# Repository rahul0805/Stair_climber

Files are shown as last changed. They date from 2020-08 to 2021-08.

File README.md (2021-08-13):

# Autonomous Stair Climber Robot

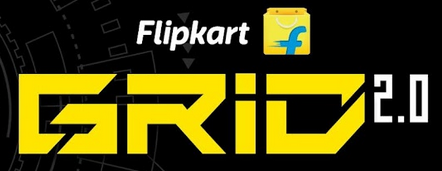
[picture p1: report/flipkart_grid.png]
 

 As a part of the competition [Flipkart GRiD 2.0 - Robotics Challenge](https://dare2compete.com/hackathon/flipkart-grid-20-robotics-challenge-flipkart-grid-20-flipkart-113687), A novel warehouse Stair Climber Bot is developed. 

It is a fully Autonomous bot which uses complex Vision Algorithms to navigate through ground and detects Stairs without the use of side railings to climb the stairs and maintain a steady trajectory and motion.

The Repository Contains the Layouts, CAD files, Stair detection code and report of the project. 

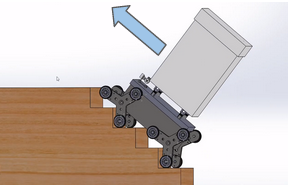
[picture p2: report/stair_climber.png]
  

## Notable Features:
* Novel Tri-Wheel Design
* Autonomously detects Stairs and Plans Path for climbing up or down the stairs  
* Fast, Robust, Maneuverable in any terrain, reliable and stable while climbing
* Autonomously detects and changes state b/w Climbing Mode and Driving Mode, independently for front and rear wheels.
* Independently looks for the next Staircase on a landing.
* Keeps payload compartment aligned horizontally always. (using linear actuators and gyro)
* Adjusts bot orientation to remain centrally aligned during Stair Climbing without use of side walls

## Report and Simulations:
* [Final Report](https://github.com/rahul0805/Stair_climber/blob/master/report/final_report.pdf)
* [Simulation Videos](https://youtube.com/playlist?list=PLahYkbmWckzONub3VNVtrBdGIVFIZ1MPK)

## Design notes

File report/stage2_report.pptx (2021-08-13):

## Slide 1

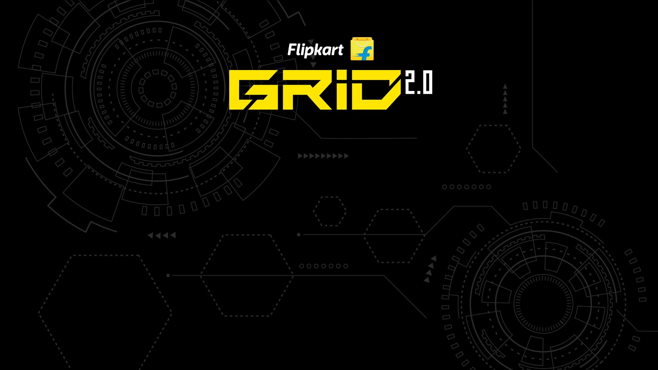
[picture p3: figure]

Autonomous Stair Climbing Robot

Team Name : LazyBot
Institute Name: IIIT Hyderabad

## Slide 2

Team members details

Team Name | LazyBot
Institute Name | International Institute of Information Technology Hyderabad
Team Members > | 1 (Leader) | 2 | 3 | 4 | 5
Name | Vedant Mundheda | Karan Mirakhor | Dipanwita Guhathakurta | Rahul Kashyap Swayampakula | Puppala Avinash Prabhu
Batch | 2023 | 2022 | 2023 | 2022 | 2022
Area of expertise | Design & Vision | Design & Mechanism | Robotics Vision & AI | Design & Sensor Placement | Control & Locomotion

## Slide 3

Functionalities of the Robot

Tri- Wheel Rotational Modes

1) Braking mechanism is engaged to cause the entire Tri Wheel to rotate about centroid.
2) Rotation occurs in the same direction as the three spinning wheels which are locked now.

1) Only the three wheels are driven to rotate in this mode.
2) Tri Wheel is able to passively pivot about its centroid to adapt for obstacles and slopes.

Driving Mode

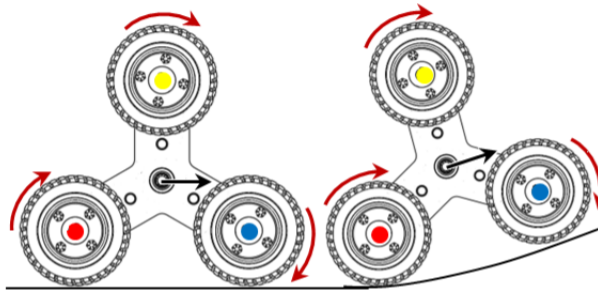
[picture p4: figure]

Stair Climbing Mode

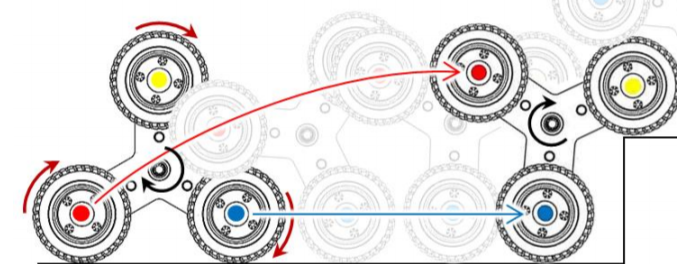
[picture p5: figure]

What all can the robot do?

Autonomously detects Stairs and Plans Path for climbing up or down the stairs

Fast, Robust, Maneuverable in any terrain, reliable and stable while climbing

Autonomously detects and changes state b/w Climbing Mode and Driving Mode, independently for front and rear wheels.

Independently looks for the next Staircase on a landing.

Keeps payload compartment aligned horizontally always. (using linear actuators and gyro)

Adjusts bot orientation to remain centrally aligned during Stair Climbing without use of side walls

Are there any things that the robot can do above and beyond the requirement?

Moves effortlessly on an inclined plane in Driving Mode.

Fast and stable on Rough and Rocky terrains.

Carry payload weight upto 25 Kg on a Staircase.

Server and an App to track the Bot’s location, sensor data, battery status etc remotely.

Climb up or down even on Curved or Spiral Staircase.

Are there any out of the box functionalities?

Overcomes scenarios in which only two wheels remain in contact with Ground.
By Toppling the wheel

Passive tumbling of the Tri wheel and Suspensions give extra stability in Driving Mode.

Simple, efficient and effective Wheel Mechanism for Stair climbing.

Prevents overload using Separate Batteries for Front and Rear wheels

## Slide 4

Robot Specifications

Technical Specs
- Ideal operation speed of the bot in Driving Mode: 8 - 10 Km/hr
- Ideal operation speed of the bot in Stair Climbing Mode: 2 - 3 Km/hr
- Max Obstacle Height it can cross over in Driving Mode: 40 cm
- Max Obstacle Height it can cross over in Stair Climbing Mode: 20 cm
- Power consumption: 180 - 1415 W
- Distance the Bot can go upto on one full charge: 7.5 - 65 Km depending upon the use case
- Turning radius: ~0 cm
- Ideal Working Scenario Endurance:
22.23 Km (70% time on flat terrain, 15% time on 45° inclined plane, 15% time in Stair Climbing)

Physical Specs
- Robot Dimensions : 50x50x96.59 cm (lxbxh)
  - Ground Clearance : 16.59cm
  - Chassis dimension : 50x50x20 cm
  - Payload box dimension : 40x40x60 cm
- Wheel design : Tri-Star wheel design
- Wheel dimensions :
  - Each wheel radius: 7.62cm
  - Spoke Length: 13.97cm
- Material used for robot body : Aluminium and plastic.
- Weight : 50kgs (without payload)

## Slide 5

Robot/Solution Limitations

Limitations other than Requirements
- Robot and Tri Wheel system is designed to operate on Staircases of 15-20 cms Height with 24-30 cm of Tread in Stair Climbing Mode.
- Speed restricted to 11 Km/hr due to the choice of Geared DC Motors for excess Torque during Stair climbing.
- It can carry a maximum payload of upto 25Kg only.
- With one full battery charge :
  - Upto 65 Km in Driving Mode on a flat terrain.
  - Upto 7.5 Km in Stair Climbing Mode
- Software Limitation : Vision algorithm works less efficiently in case of curved stairs.
We rely on Ultrasonic Sensor Data and IMU to climb Curved stairs.

No Limitations compared to the Requirements!!

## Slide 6

Robot Design

Robot Top View

Wheel Design

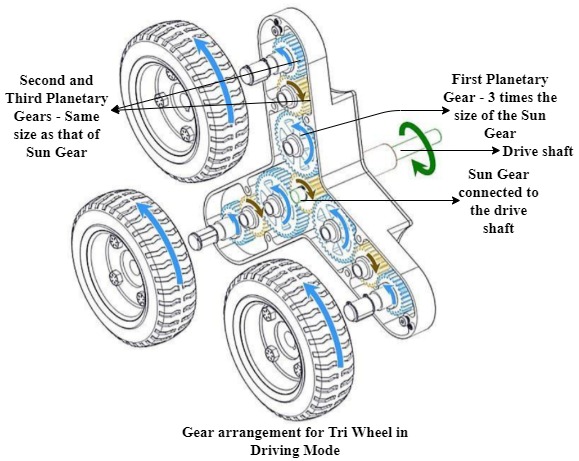
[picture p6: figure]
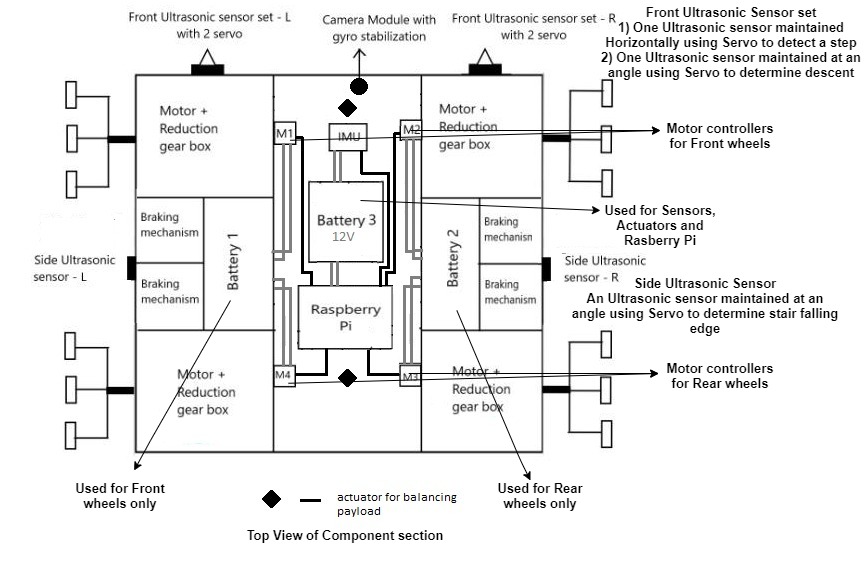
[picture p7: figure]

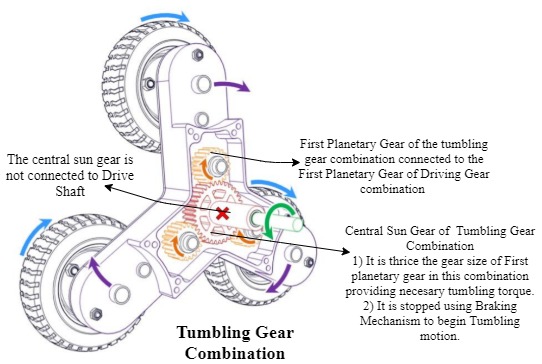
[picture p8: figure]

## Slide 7

Robot Side View

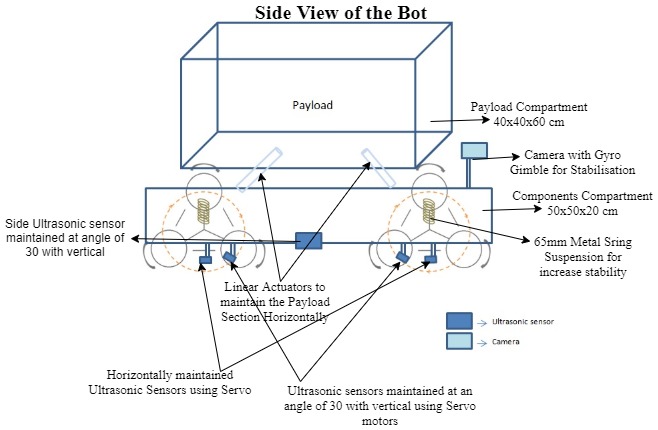
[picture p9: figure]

Robot Front View

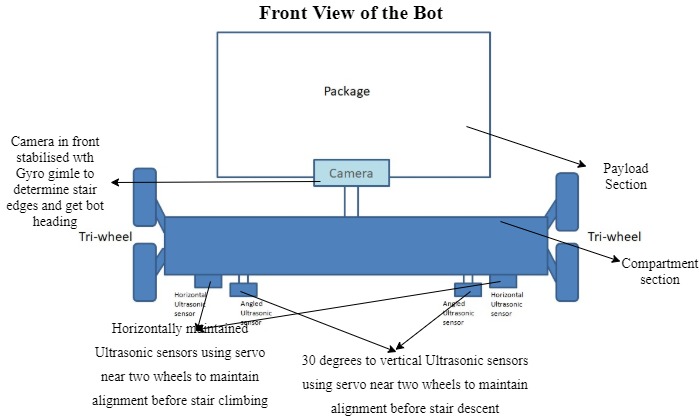
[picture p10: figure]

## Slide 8

Architecture

The diagram describes how the electrical modules are connected in the bot. And explains the transfer of different signals among the modules at a higher level.

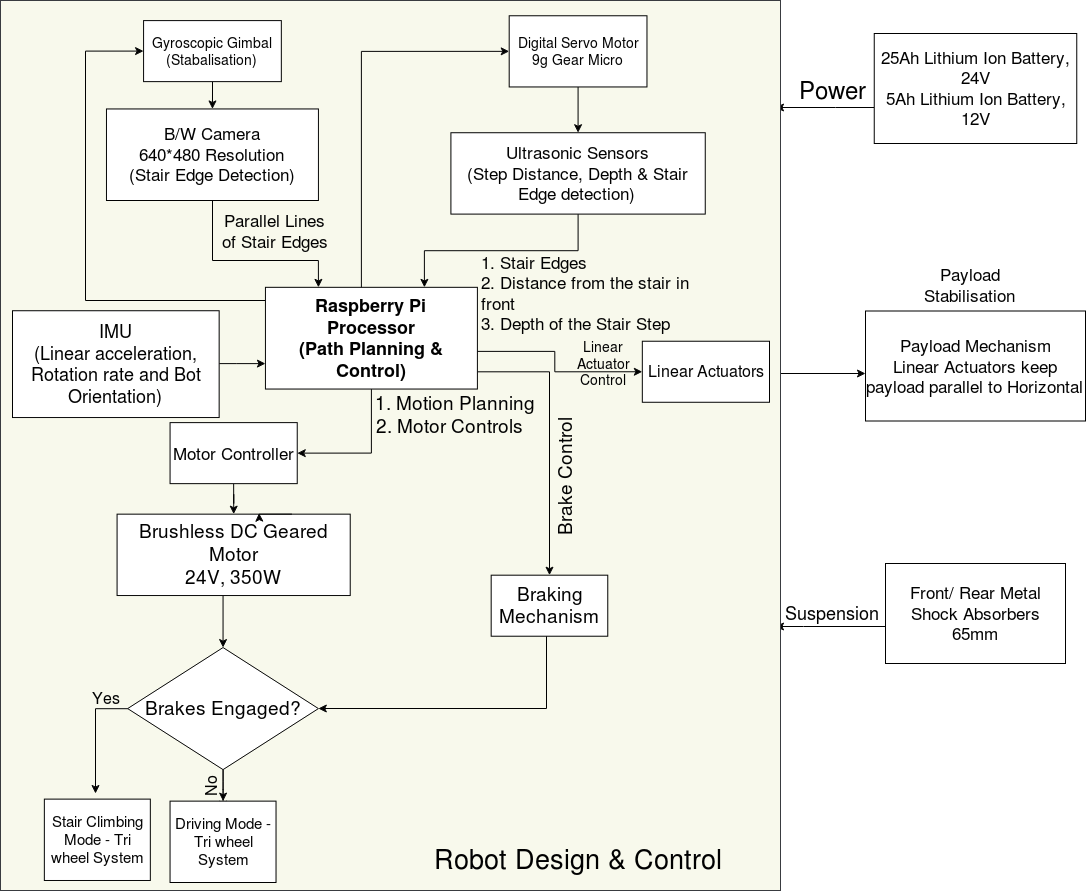
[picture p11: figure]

Note: The Motors and brakes are connected to wheels and linear actuators are used to stabilise payload. The power lining is explained in the previous slide.

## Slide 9

Python Modules to be built (for stair detection through image processing):
- Gabor filter: using OpenCV’s inbuilt getGaborKernel, filter2D.
- Edge detector: using OpenCV ’s inbuilt Canny edge detector.
- Edge linking: to be coded from scratch using Python.
- RANSAC: using skimage’s inbuilt ransac.
Estimated overtime of the system is less than 60 ms

Custom built modules to control the various hardware components:
- Program to control the various states(rolling, ascending, descending) by processing the inputs from the ultrasonic sensor, IMU and gyroscope and controlling the brakes.
- Program in the Microcontroller which will control the wheels (taking turns) based on the current state and path plan.
- Program for the autonomous orientation of robot in the direction of the next stairway by processing distance inputs from lateral ultrasonic sensors at the quarter-landing.

Brief on Programming Module

Programming language used:
Python

Raspberry Pi modules to support hardware:
- GPIO support on Raspberry Pi: RPi.GPIO for the HC-SR04 ultrasonic sensor.
- Raspberry Pi Camera module: Picamera to capture to get a stream of images of the staircase.

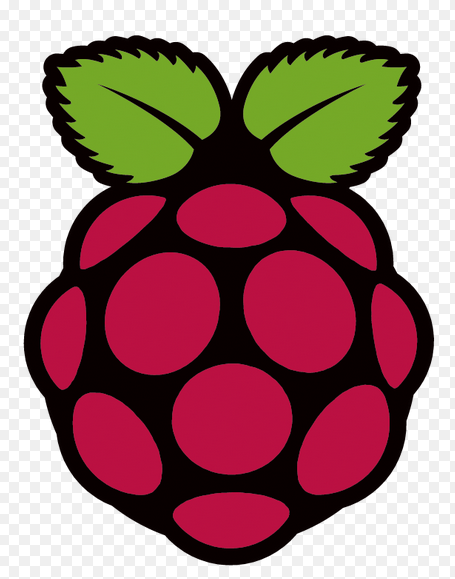
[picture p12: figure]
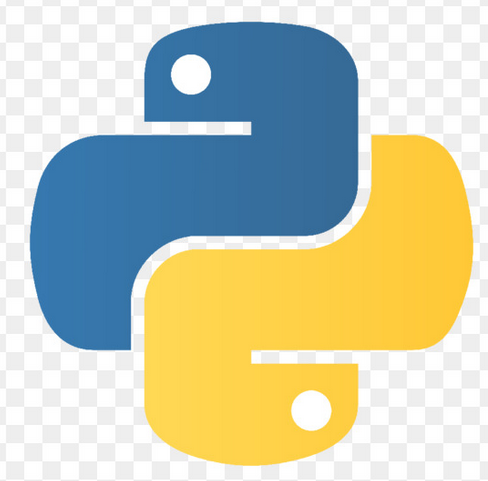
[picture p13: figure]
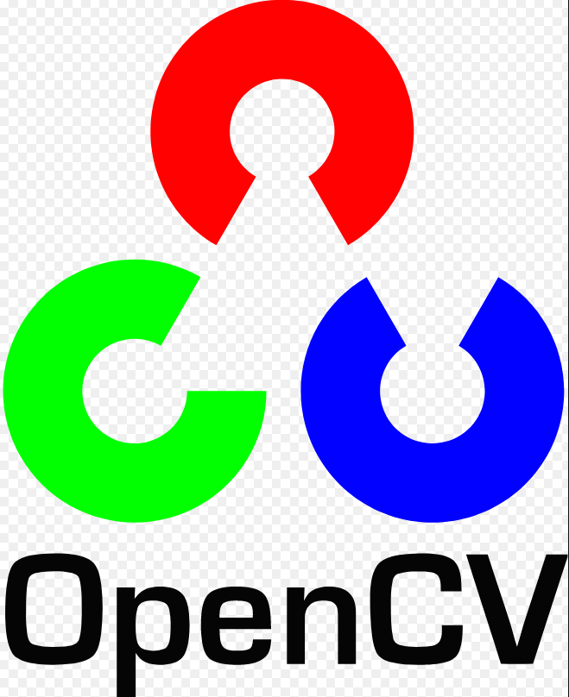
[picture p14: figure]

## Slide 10

Execution Plan

Exploring various solutions based on cost, feasibility, etc.
(July 1-2)

Making a list of the requirements for a particular solution.
(July 3-4)

Drawing a rough sketch sketch of the bot and the algorithm flowchart
(July 5-7)

Making CAD model of proposed Design using Solidworks and developing code.
(July 8-17)

Order the parts required for the robot.

Testing the robot in simulation
(July 18-25)

Assemble the hardware

Improving the algorithm and design based on the results
(July 26-29)

Cost Estimation
1. Brushless DC Motor 350W 4 x ₹ 3,600
2. Motor Controller - 350W 4 x ₹ 800
3. 25Ah 24V Li ion Battery 2 x ₹ 7,500
4. 5Ah 12V Li ion Battery 1 x ₹ 500
5. Chassis Assembly ₹ 1,500
6. Wheel Assembly 4 x ₹ 2,500
7. Raspberry Pi 3 ₹ 3,000
8. Camera Module ₹ 600
9. Sensors and Actuators ₹ 6,000
10. Suspension system ₹ 2,500
Total ₹ 56,200

Testing the Algorithm on the board and verifying the commands without body.

Note:
Tentative Timeline

Testing the hypothesis on the bot

Done

In Progress

Yet to start

Improving the results

Final submission

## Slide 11

Autonomous climbing using Vision Algorithms

- Gabor Filter used:
Eliminate influence of illumination
Keep Stair Edges
- Generic edge detector on filtered image:
Removes small, vertical edges.
- Remainder adjacent edges linked into horizontal parallel edges (Stair edges)
Midpoints of horizontal lines estimated.
- A line is fitted joining centres of detected stair edges by RANSAC method (white line in Fig 4) and 2 offset parameters are estimated w.r.t robot orientation (blue line in Fig 4):
θ = angle b/w bot orientation and the line joining centres of detected edges
Δx = distance b/w bot orientation and line joining centres of detected edges
- If θ and Δx are less than a fixed threshold, maintain previous orientation, else change direction to minimise θ.

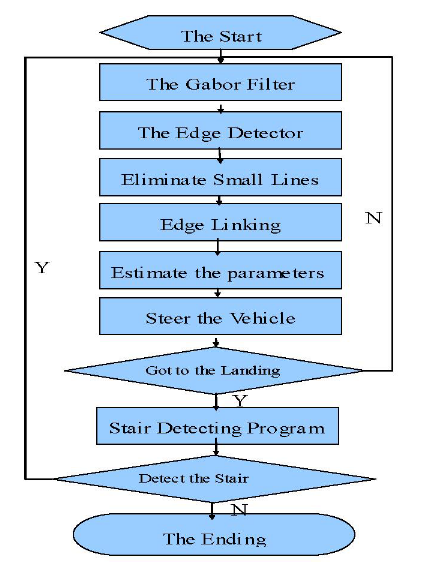
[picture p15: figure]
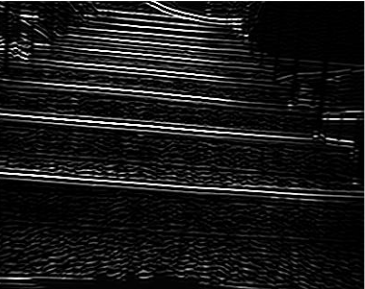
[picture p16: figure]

Fig 1: Output of Gabor filter
Fig 2: Output after eliminating small vertical edges
Fig 3: Output after edge-linking
Fig 4: Demonstration of calculating offset parameters

These are references ref_1 (https://www-users.cs.umn.edu/~stergios/papers/stair_climbing_IROS02.pdf), ref_2 (https://ieeexplore.ieee.org/document/4525517), ref_3 (https://www.semanticscholar.org/paper/Stairs-Detection-Algorithm-for-Tri-Star-Wheeled-and-Thu/edd12c81adde5f042a3efe1b880fa853c86bb46e)

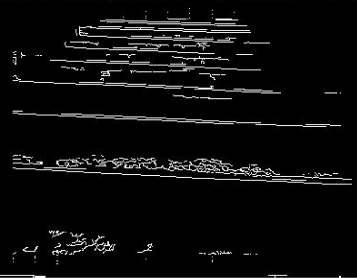
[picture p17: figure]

Fig1

Fig2

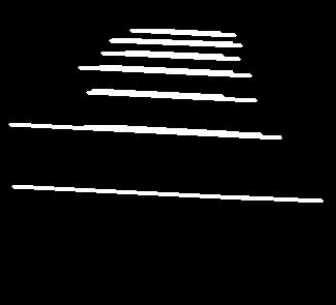
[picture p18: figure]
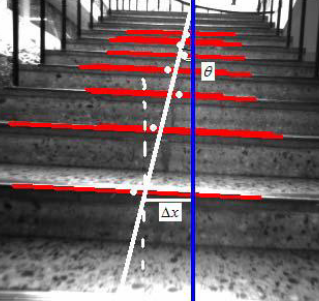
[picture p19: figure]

Fig3

Fig4

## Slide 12

Control flow

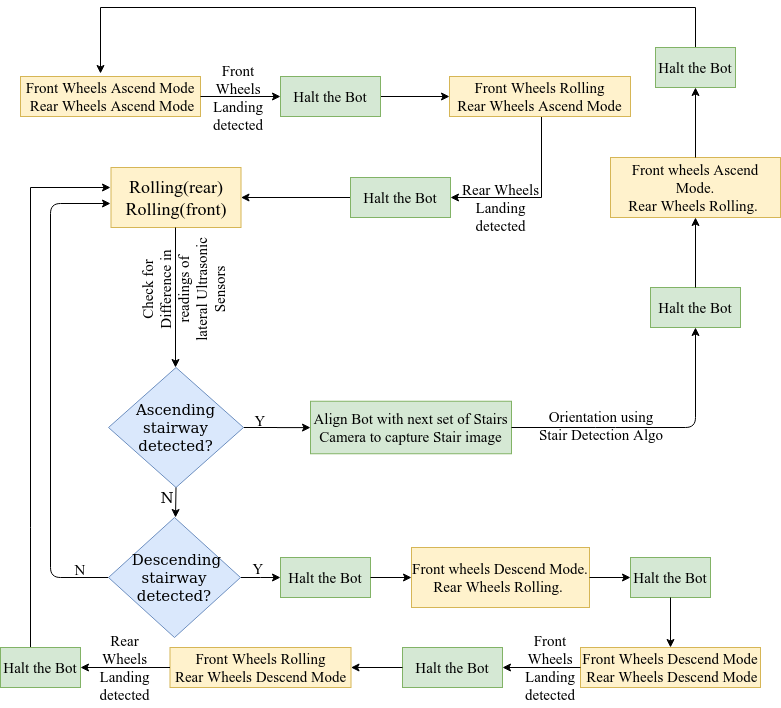
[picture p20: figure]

θ= 0 degrees
d <= a
x <=y
Increase power

Rolling

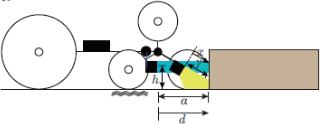
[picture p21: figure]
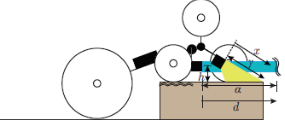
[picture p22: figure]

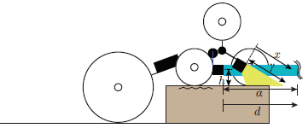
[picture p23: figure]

θ: gyroscope reading to get angle above horizontal
d: Distance in front through ultrasonic sensor
x: Inclined distance through ultrasonic sensor

State switching logic for wheels

Ascending

θ= 120 degrees
d > a
x <=y
Normal power

Ascending

θ= 0/120 degrees
d > a
x > y
Decrease power

State transitions for each set of wheels

Rolling

Rolling

Descending

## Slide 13

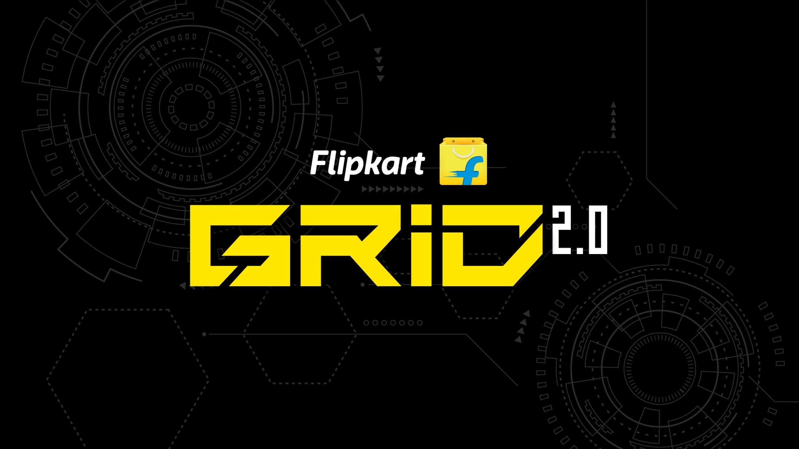
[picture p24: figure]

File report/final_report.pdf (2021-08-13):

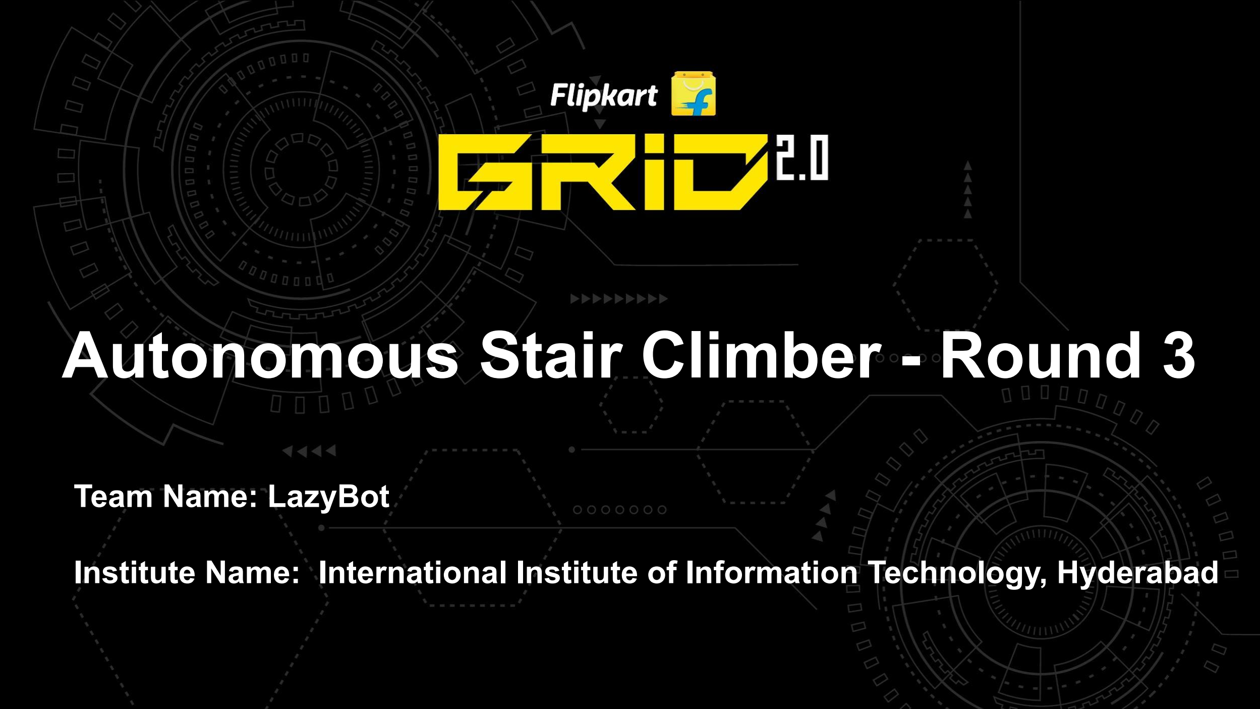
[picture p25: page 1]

# Autonomous Stair Climber - Round 3

## Team Name: LazyBot

## Institute Name: International Institute of Information Technology, Hyderabad

# Team Member details

### Vedant Mundheda

### Karan Mirakhor Rahul Kashyap Swayampakula

Dipanwita
Guhathakurta

Puppala Avinash
Prabhu

Undergraduate
Researcher at Robotics
Research Centre(IIIT
Hyderabad)

Undergraduate
Researcher at
Robotics Research
Centre(IIIT
Hyderabad)

Undergraduate
Researcher at
Robotics Research
Centre(IIIT
Hyderabad)

Undergraduate
Researcher at
Robotics Research
Centre(IIIT
Hyderabad)

Undergraduate
Researcher at
Robotics Research
Centre(IIIT Hyderabad)
| Cleared 3 levels in E-yantra Robotics competition | Cleared 3 levels in E-yantra Robotics competition
Working on Aerial Manipulator Project | Working on Aerial Manipulator Project | Working on Aerial Manipulator Project | Working on Collision Avoidance in Dynamic Environments | Working on estimating free space in a warehouse environment.

# Assembly

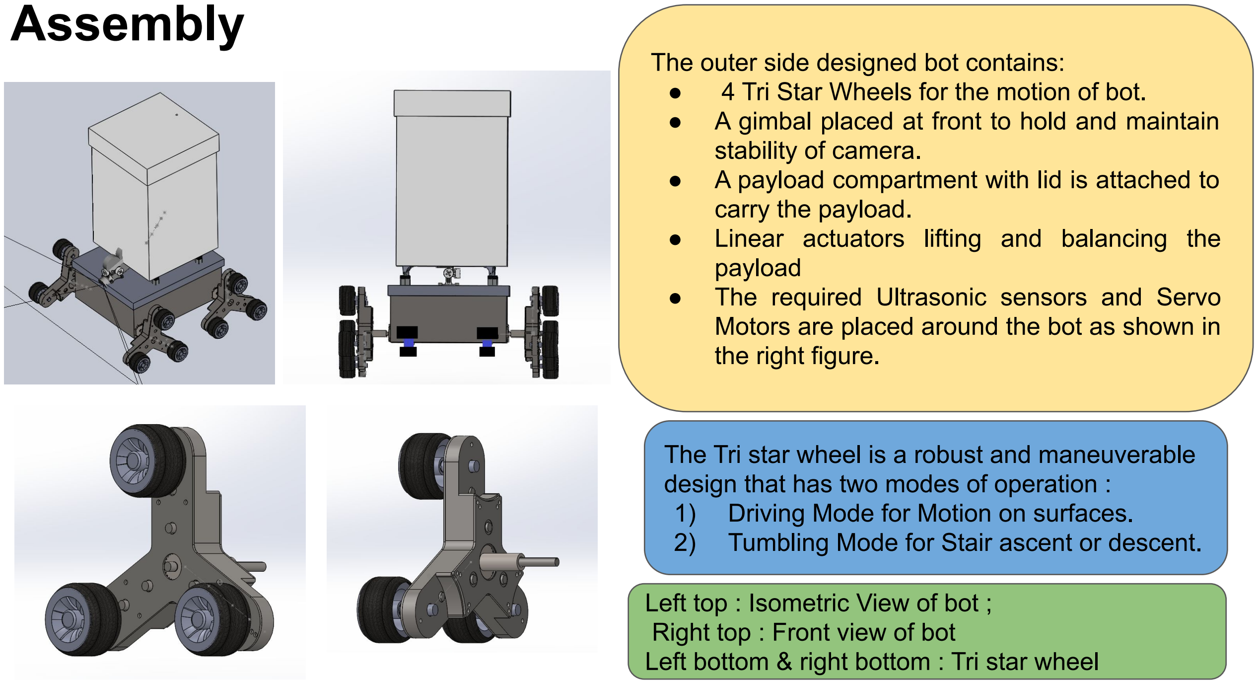
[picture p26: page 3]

The outer side designed bot contains: ● | 4 Tri Star Wheels for the motion of bot. ● | A gimbal placed at front to hold and maintain

stability of camera.
- A payload compartment with lid is attached to carry the payload.
- Linear actuators lifting and balancing the payload
- The required Ultrasonic sensors and Servo Motors are placed around the bot as shown in the right figure.

Left top : Isometric View of bot ;
Right top : Front view of bot
Left bottom & right bottom : Tri star wheel

The Tri star wheel is a robust and maneuverable design that has two modes of operation :
1) Driving Mode for Motion on surfaces.
2) Tumbling Mode for Stair ascent or descent.

# Wheel Design


Driving Mode Design
1) The Motor Shaft is directly connected to the central driving gear.
2) Central driving gear is linked to the Large Driving gears (Gear Ratio 1:3).
3) These Large Driving Gears are linked to the Idler gears (Gear Ratio 3:1).
4) Now, these Idler gears are linked to the Main driving gears which are connected to the wheel shaft.
5) This gear design ensures that motor speed and torque is directly delivered to all three wheels simultaneously in this mode..
6) Simulation link : https://youtu.be/Z-jkf5voGJo


Tumbling Mode Design
1) The Central tumbling Gear is NOT linked to the motor drive shaft.
2) The Central tumbling gear is linked to the Small Tumbling gear (Gear Ratio 3:1).
3) These small tumbling gear is linked to the Large driving gears.
4) Now when we lock the Central Tumbling Gear using Braking Mechanism, the whole Tri Wheel is constrained to rotate about its Central axis.
5) This Gear Design ensures three times the Motor torque during Tumbling.
6) Simulation link : https://youtu.be/PUGKdtVIjqo

# Wheel motion

The leftmost Tri-Wheel instance in Figure (left side) begins in Driving Mode with all three wheels spinning in a clockwise direction. The arrow encircling the centroid of the mechanism indicates the initiation of the braking mechanism to induce tumbling.

As the Tri-Wheel body begins to rotate about its centroid, it simultaneously continues to translate in a horizontal direction, as indicated by the blue horizontal arrow. As the leading (blue) wheel rolls forward on the flat surface, the top THE TRI-WHEEL MECHANISM (yellow) wheel begins to rotate forward and lands on the first step and assumes the position as the new leading wheel. At this point, the leading (yellow) wheel rolls forward. As the leading (yellow) wheel approaches the next step, the top (red) wheel swings over top of the yellow wheel and lands on the next step. The pattern continues as the Tri Wheel
mechanism effectively “walks” itself up the set of stairs.
Ascending | Descending

# Robot views ( Showing Electronic Components )


Camera in Front stabilized by Gyro Gimle to determine stair and Bot direction

Package

Tri-Wheel

Payload
Section

Horizontally Maintained
Ultrasonic Sensors | 30 degrees to vertical
| Ultrasonic sensors using servo
| near two wheels to maintain
| alignment before stair descent
Front View of the bot | Top view of the bot

# Architecture

## The diagram describes how the


## electrical modules are connected in the bot. And explains the transfer of different signals among the modules at a higher

level.

## Note: The Motors and brakes are connected to wheels and linear actuators are used to stabilise payload. The power lining is

explained in the previous slide.

Emergency
shutdown
signal receiver

# Stair detection using YOLO(You Only Look Once)

Running Time; Precision; Recall; Confidence Threshold; IOU Threshold; YOLOv5; Full video at:; shorturl.at/pLR01

Results after training YOLOv5

We used YOLOv5 to extract the
portion of the image in which the stairs
are present.

Train set Size

Training Image Size

Results on Test

# Vision Algorithm for ascending (Planning and Perception)

We run edge detection, linking and line fitting algorithm in real-time on the portion of image within the bounding box (refer slide 10). This eliminates the side wheels and the bot body from the camera image.

Final output after running YOLO and this algorithm on our simulation

➔ | The red rectangle denotes the bounding box showing
| confidence of stair detection by YOLO.
➔ | The white lines denote stair edges.
➔ | The red points are midpoints of obtained edges.
➔ | The central red line denotes the desired heading
| orientation.

### Perception and Path Planning

- We obtain a fitted line denoting the desired orientation of the bot, compare it with the current bot orientation via the IMU and steer the bot towards the desired orientation using a PID controller.
- If the slope of the planned path is greater than a certain threshold, we use the previous frame’s slope

Full video at: https://youtu.be/ctwr45Y9hrs

Vision Algorithm while Descending; the side edges.; Simulation; Stair edges and fitted line; Perception and Path Planning; We run edge detection, linking and line fitting algorithm in real-time.

We put thresholds (abs(slope) < 0.05) for slopes of detected stair edges to eliminate

We obtain a fitted line denoting the desired orientation of the bot, compare it with the
current bot orientation via the IMU and steer
the bot towards the desired orientation using
a PID controller. | Simulation Video : shorturl.at/hFIUW

# Edge detection, linking and desired heading

### - Gabor Filter used to eliminate


### influence of illumination

## - Canny edge detector on filtered image

gives all edges in the image.

## - Connected Components used to group

### nearby edges into components and

assign hue values to each.

### - Adjacent connected components are linked into long horizontal edges(stair edges) - Midpoints of horizontal linked stair

edges estimated.

### - fitLine fits a line to the midpoints of stair edges based on the M-estimator (http://en.wikipedia.org/wiki/M-estimator ) technique that iteratively fits the line using the weighted least-squares algorithm

Original
Grayscale
Image

Filtering
through
Gabor
filter

Canny
edge
detection

Edge
linking
and line
fitting

Full notebook at:
https://github.com/susiejojo/Stair_Climber/blob/master/stairclimber_vision3.ipynb (https://github.com/susiejojo/Stair_Climber/blob/master/stairclimber_vision3.ipynb)

# Distance and Depth Algorithms

θ= 0 degrees
d <= a
x <=y
Increase power

Rolling Ascending

θ= 120 degrees
d > a
x <=y
Normal power

Ascending Rolling

θ= 0 / 120 degrees
d > a
x > y
Decrease power

Rolling Descending

Motion on stairs of varying size is not easy in general. Proposed design can accomplish this task with ease !!

Distance to stair

While climbing, the front wheel of the bot should be less than 5 cm from the starting of the stair. In that case the bot can easily climb 30cm or more. This is verified by placing ultrasonic sensors at the front of the bot with a calibrated distance. If the distance is more than threshold the bot enables driving motion to reduce the distance between stair and bot.

Depth detection

While descent bot needs to know that there are descending stairs and know the depth it is achieved by placing a tilted ultrasonic sensor. As we know the orientation of sensor from the calculated distance of ultrasonic sensor we can
get depth of the surface.

Distance_detected = ultrasonic_measurement

Depth_detected = [(distance_detected)*cos(orientation_angle)] - (sensor_height)

Component | Name | Purpose

# Electronic Components

Microcontroller | Raspberry Pi 3 | Image Processing, Path Planning and
| | | Control
Ultrasonic Sensors | HC-SR04 connected via voltage dividers to Raspberry Pi | Depth and distance estimation
DC GEARED Motor | EBIKE MY1016Z3 Brushless DC geared motor(24 V, 350 W) | Regulating wheel motion
Gyroscopic Gimbal | | Stabilize the camera in case of jerky motion
Camera | Raspberry Pi camera module
Motor controller | 24V for MY1016 350W
RF circuit | Emergency remote


Circuit diagram denoting connection of Raspberry Pi with IMU, a single Ultrasonic sensor and DC motor with motor controller

# Load Stability

Ref_orientation( 0 deg); Bot_orientation (IMU value); Orientation - motor algo M1 = K*(diff) M2 = K*(diff) M3 = -K*(diff) M4 = -K*(diff); Controller; Actuator; Ascending; Descending

The Load Stabilization is done using
Linear Actuators. The orientation of the
payload is aimed to maintain payload
orientation parallel to the ground.

Reason:
- Reduces the torque about the wheel
- Prevents unnecessary movement of
the load inside the box.

WIth all these mechanisms the bot
can carry a maximum payload of

# Payload Calculations

Torque calculations f bot without
payload(50-55kg)
Mode | Torque on each motor
| On plane ground
Driving | >=0.37 N-m
Tumbling | >= 18 N-m

45 degree inclination

Tumbling; The calculations are based on the assumption that coefficient of friction between wheel and ground : 0.025 and gravity : 9.8 m/s^2; The operating torque without payload : 14-16 N-m.The operating torque without payload : 18-20 N-m.; The torque vs speed calculations are done for 24v 350W motors (mentioned in components) assuming 80% gear efficiency.

Driving | >=8.08 N-m

Torque calculations of bot with maximum payload(75-80 kg)

Mode | Torque on each motor
| On plane ground
Driving | >=0.5 N-m
Tumbling | >= 24 N-m

45 degree inclination

Driving | >= 9.899 N-m

Torque vs speed calculations (Non -ideal)

Torque (N-m) | Speed (kmph)
14 | >=5.833
13 | >=6.28
12 | >=7.6
11 | >=8.618
8 | >= 9.6

# Power consumptions details

● Maximum Power consumption: 334.74W; Motor consumption; @ 11Nm Working Scenario :; plane + 15% Stair Climbing = 0.7x2x324/60 + 0.15x9x324/60 + 0.15x11x324/60 = 23.76W; Sensors, Actuators & Camera; Current 5 mA, Standby Current @ 14uA = 0.2W. 2) Raspberry Pi 3 250mA @ 5V= 1.25; 2A = 96W 4) 6 - Servo Motors 5V @200mA = 6W. 5) Raspberry Pi 3B - 5V @ 250mA 1.25W

- Distance the Bot can go upto on one full charge: 7.5 - 65 Km depending upon the use case

24V 350W geared DC motor rated @ 324 RPM

1) 90% Stair Climbing + 10% on Flat Surface
2) 70% Flat Surface + 15% @45 Deg incline
1) 8 - Ultrasonic Sensors 3.3V - 5V @ Operating
3) 4 - Linear Actuators (for 5Kg Payload) - 12V @

Total Sensors, Actuator & Camera Power =

# Detailed Activity timeline


State transitions
for each set of
wheels

# User Interface

Payload placement : A separate compartment is made for payload, user should place the payload in the compartment provided and close the compartment with the lid. A clip mechanism or more advanced locking system will be provided to close the lid of the compartment.
Charging the bot: A charging port is provided connecting all batteries inside the bot. A 48V charger can be used to charge the bot.
Setting up the bot :
- A power switch will be provide to ON/OFF the robot.
- It is advised to place bot where it has a good view of the stairs
- In case of long journey one needs to provide starting and ending locations
Recovery mode: If the bot malfunctions it can be shut down using the emergency remote by standing at safe distance (max 500m) or it can be manually shut down using power switch of the bot.
If Bot detects any system failure then it alarms user, the user may shut it down using power or emergency shut down.

Charging Port

Payload Placement

Switch

Emergency Shutdown

# Recovery Mode Design

If there is an obstacle in the path of travel the robot the robot comes to rest in no time by applying brakes

If the bot is running out of charge while climbing stairs it uses its backup energy to hold the bot at the state to prevents falling and also alarms user about the charge.

From the taken measures and design of the bot there is very low chance of falling of the bot, but if it accidentally falls:

- The designed compartment contains shock absorbers will give good protection for the payload and avoid any damage to it.
- In case if the bot falls down, it detects it according to reading of IMU and immediately system failure will be alarmed to user.
- If the bot malfunctions it can be immediately shutdown using the Emergency shutdown remote provided or by turning off the power switch on the bot. This system is designed using 500+m LOS range with 2.4Ghz radio
- Additional fire detection also can be done by deploying temp sensors

# Simulation/Videos

The motion simulations are done in Solidworks 2016. We chose Solidworks because of its robust physics engine which helped us to simulate accurately.

Links showing gears rotation in rolling and tumbling mode of bot:
- Rolling mode : https://youtu.be/Z-jkf5voGJo
- Tumbling mode : https://youtu.be/PUGKdtVIjqo

Links of the Bot ascending and descending on stairs and switching between states based on the situation:
- Rolling on plane ground : https://www.youtube.com/watch?v=KaJuw24jhKU
- Tumbling on stairs : https://youtu.be/Me_sMcBY8to

Output of the Stair Detection Algorithm
- Camera output while ascending stairs : https://youtu.be/ctwr45Y9hrs
- Camera output while descending stairs : https://youtu.be/GUMBIVCMhro Cad models
- https://github.com/karan-13-hub/Tri-Wheel-Design
- https://github.com/karan-13-hub/Stair-Climber

Explain ease of portability of the bot; The bot has advantage of eight wheels. As it has eight wheels the total force is distributed across eight wheels so this makes bot move in any terrain.; Indoors the bot can easily avoid any climb any small obstacle to big steps in the way of its transport because of its tumbling mode of motion. It can also be carried outdoors in rocky, muddy or sandy terrain.; Distributed weight; Robustness to terrains; Even if the weight of bot is bit high it is easily movable because of the amazing wheel design.; Support for large weights

Speed and time of travel; ● Ideal operation speed of the bot in Driving Mode: 8 - 10 Km/hr ● Ideal operation speed of the bot in Stair Climbing Mode: 2 - 3 Km/hr; ● With full speed the bot can climb up the 15 stairs of thread 30 cm and height 20 cm within 10 sec (ideally) ● The vision algorithm has latency of 0.104 sec per frame; ● Max Obstacle Height it can cross over in Driving Mode: 40 cm ● Max Obstacle Height it can cross over in Stair Climbing Mode: 20 cm ● Turning radius: ~0 cm; With 20 frames per second the bot takes; descent it takes 40-50 sec.

30-40 sec to cimb up the stairs. And for the

Details of Electrical Components

Component | Price/unit | No of units | Source | Total Price
Brushless DC Motor 350W | ₹3500 | 4 | Roland_electro nics(HYD) | ₹14000
Motor Controller - 350W | ₹897 | 4 | Controller (https://robu.in/product/motor-controller-for-my1016-350w/) | ₹3596
25Ah 24V Li ion Battery | ₹7500 | 2 | Battery (https://www.indiamart.com/proddetail/24v-25ah-lithium-ion-battery-19410985112.html) | ₹15000
5Ah 12V Li ion Battery | ₹667 | 1 | small_battery (https://www.amazon.in/Lithium-Rechargeable-Battery-Industrial-Equipment/dp/B085BGS7HK?hvadid=397083069050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) | ₹667
Raspberry Pi 3 Board | ₹2575 | 1 | Board (https://www.electronicscomp.com/buy-raspberry-pi-3-model-b-plus-india) | ₹2575

Total Estimated Cost; Electrical Components: ₹42,490 Mechanical Components: ₹14000; Net Total :

Camera Module | ₹410 | 1 | Camera (https://robu.in/product/raspberry-pi-camera-module/) | ₹410
Ultrasonic Sensor (HC-SR04) | ₹99 | 6 | Sensor (https://www.flipkart.com/sunrobotics-hc-sr04-ultrasonic-distance-sensor/p/itmf2kvfvshgy7yk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) | ₹594
Servo Motors-1 | ₹329 | 2 | Servo (https://robu.in/product/towerpro-mg995-servo-high-speed-digital-metal-gear-ball-bearing-torque-12kg-robot-arduino-good-quality180-degree-rotation/) | ₹658
Servo Motors Mini | ₹99 | 6 | Servo_mini (https://robu.in/product/towerpro-sg90-9g-mini-servo-9-gram/) | ₹594
Linear Actuators | ₹1000 | 4 | Roland_electro nics(HYD) | ₹4000
Total Cost: | | | | ₹42,490

Details of Mechanical Components

Item | Price/uni
t

No.of
units

Source Total
price
Tri-star wheel | ₹2500 | 4 | Makers Lab IIITH | ₹10000
Chassis with payload box | ₹4000 | 1 | Makers Lab IIITH | ₹4000
Total: | | | | ₹14,000

# Execution Plan

Making a list of the requirements for a particular solution. (July 3-4); Testing the robot in simulation (July 18-25); Order the parts required for the robot.; Assemble the hardware; Improving; the results; Final submission; Done; In Progress; Note: Tentative Timeline

Drawing a
rough sketch
sketch of the
bot and the
algorithm
flowchart
(July 5-7)

Exploring
various
solutions
based on cost,
feasibility, etc.
(July 1-2)

Making CAD model
of proposed
Design using
Solidworks and
developing code.
(July 8-17)

Improving the
algorithm and
design based on
the results
(July 26- Aug 29)

Testing the
Algorithm on the
board and verifying
the commands
without body.

hypothesis
on the bot

Yet to start

# References

- https://ieeexplore.ieee.org/document/8675676
- https://ieeexplore.ieee.org/document/4525517
- https://www-users.cs.umn.edu/~stergios/papers/stair_climbing_IROS02.pdf
- https://ieeexplore.ieee.org/document/4525517
- https://www.semanticscholar.org/paper/Stairs-Detection-Algorithm-for-Tri-Star-Wheeled-and-Thu/edd12 c81adde5f042a3efe1b880fa853c86bb46e (https://www.semanticscholar.org/paper/Stairs-Detection-Algorithm-for-Tri-Star-Wheeled-and-Thu/edd12c81adde5f042a3efe1b880fa853c86bb46e)
- https://www.researchgate.net/publication/256942417_Mechanical_design_and_development_of_tri-star_wheel_system_for_stair_climbing_robot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 (https://www.researchgate.net/publication/256942417_Mechanical_design_and_development_of_tri-star_wheel_system_for_stair_climbing_robot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)
- https://ieeexplore.ieee.org/document/6385776
- https://pdfs.semanticscholar.org/08da/dc36b96498615f18864662fd2184e193a7bb.pdf?_ga=2.2069713 55.998524130.1593947392-395077216.1593947392 (https://pdfs.semanticscholar.org/08da/dc36b96498615f18864662fd2184e193a7bb.pdf)
- https://www.semanticscholar.org/paper/The-Tri-Wheel%3A-A-Novel-Robot-Locomotion-Concept-the-Smith/2bb16204150b9640cbf8016b86c908ccab08f634 (https://www.semanticscholar.org/paper/The-Tri-Wheel%3A-A-Novel-Robot-Locomotion-Concept-the-Smith/2bb16204150b9640cbf8016b86c908ccab08f634)

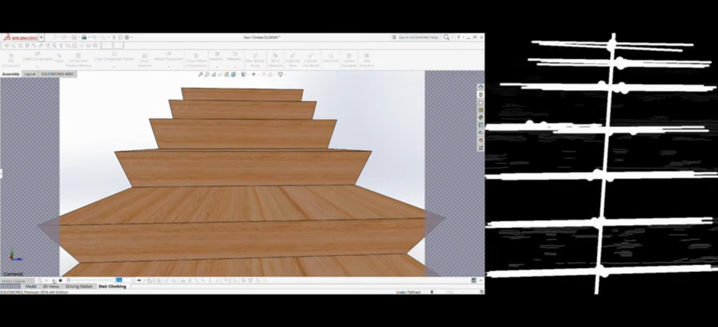
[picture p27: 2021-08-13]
report/cam_output.png

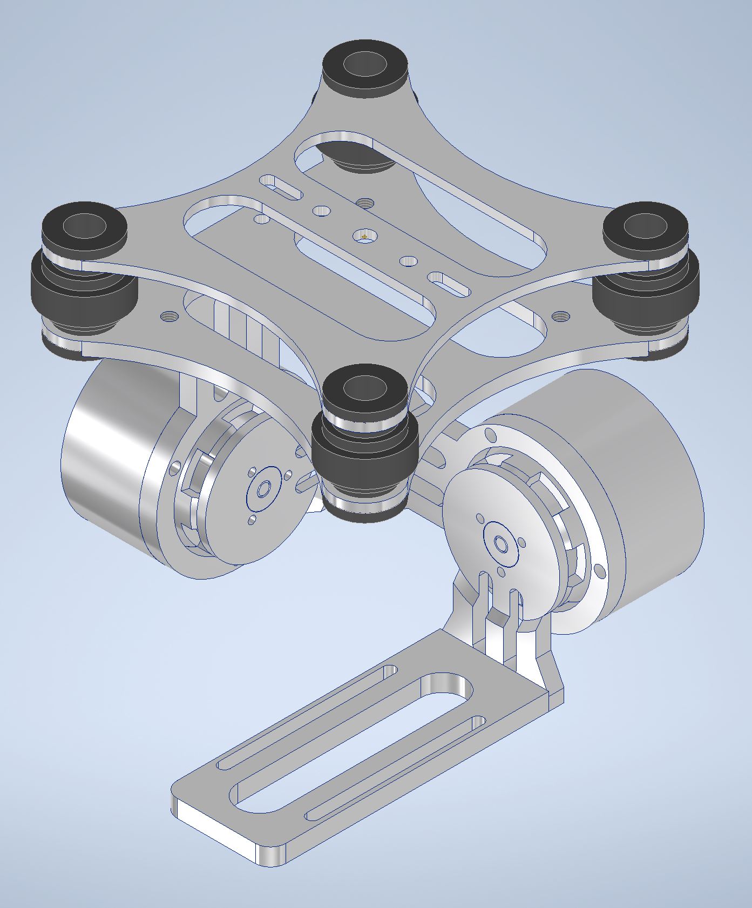
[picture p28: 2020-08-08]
Gimbal/Gimbal.JPG

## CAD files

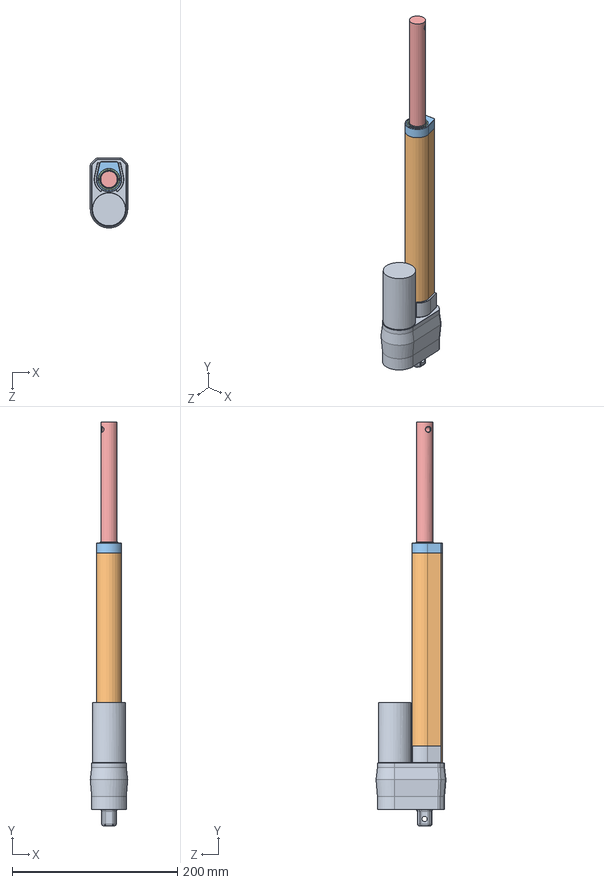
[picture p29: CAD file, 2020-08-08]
Linear Actuator/HDA-8-2.SLDASM
45.5 x 489.2 x 84.8 mm
HDA-BASE
HDA-SHROUD
HDA-SHROUD-CAP
HDA-CAP-SEAL
HDA-STROKE

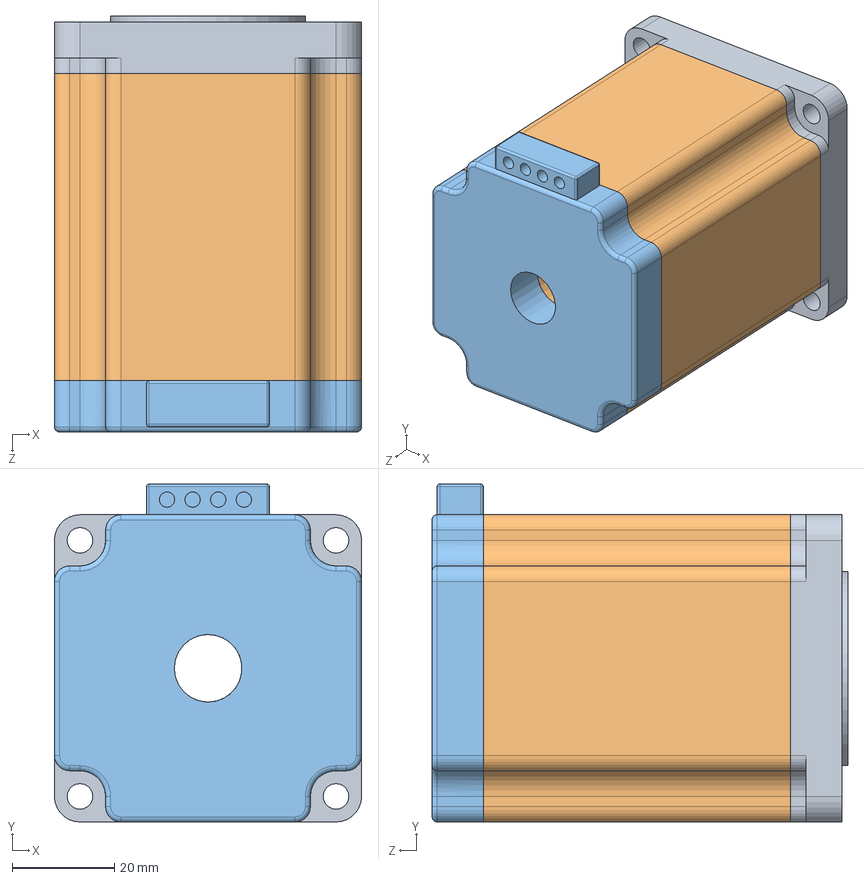
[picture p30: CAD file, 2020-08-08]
Motor Assembly/nema 24.SLDASM
60.0 x 66.0 x 81.2 mm
one
midd
last one

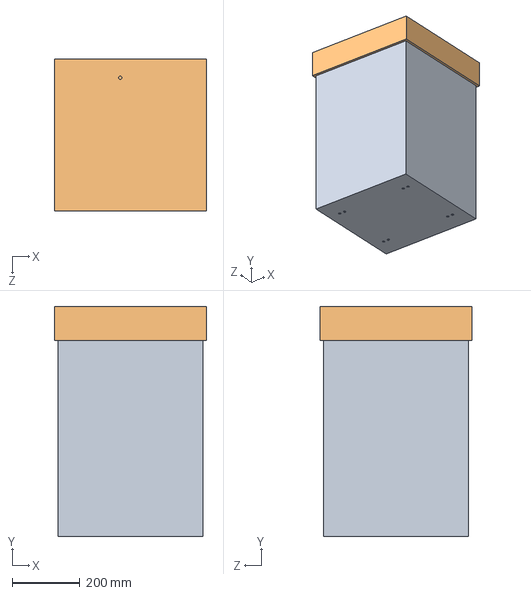
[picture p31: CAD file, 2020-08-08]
Payload Box/payload_box.SLDASM
450.0 x 680.0 x 450.0 mm
payload_bottom
Part1^payload_box

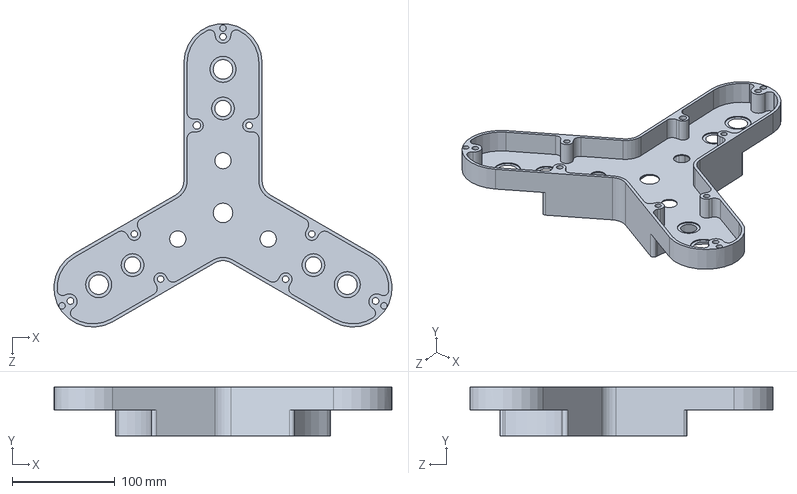
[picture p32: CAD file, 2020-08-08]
Tri Wheel/Casing/Main Casing.SLDPRT
328.9 x 47.6 x 295.0 mm

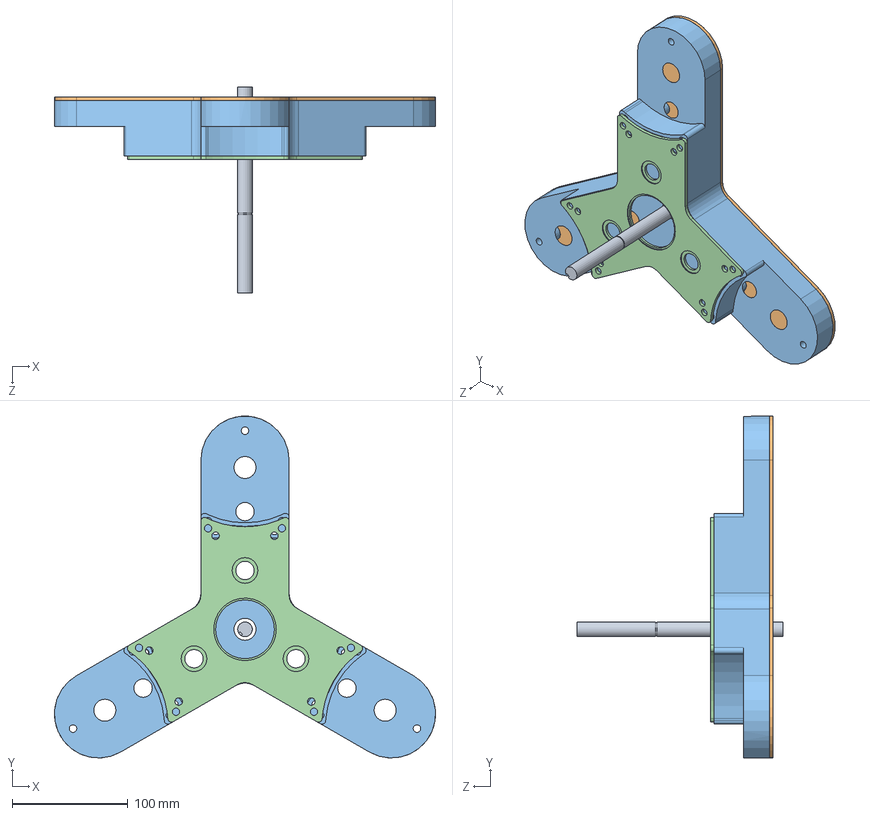
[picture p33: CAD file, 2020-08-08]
Tri Wheel/Tri Wheel Assembly.SLDASM
329.0 x 295.2 x 177.8 mm
Shaft A
Carrier_Drive Plate
Main Casing
Carrier_tumble

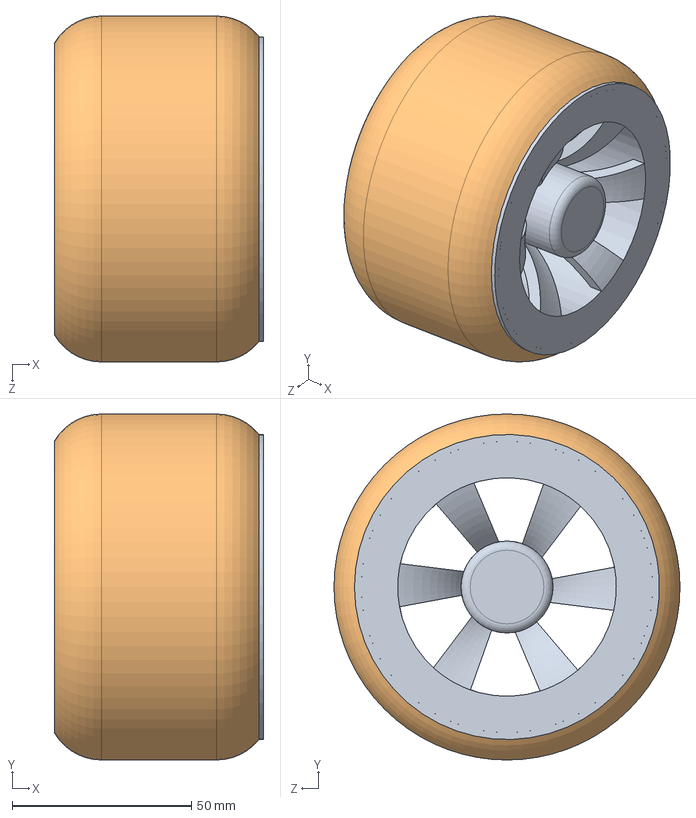
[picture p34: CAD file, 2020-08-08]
Tri Wheel/Wheels/wheel_total.SLDASM
58.4 x 96.5 x 96.5 mm
wheel
top_wheel

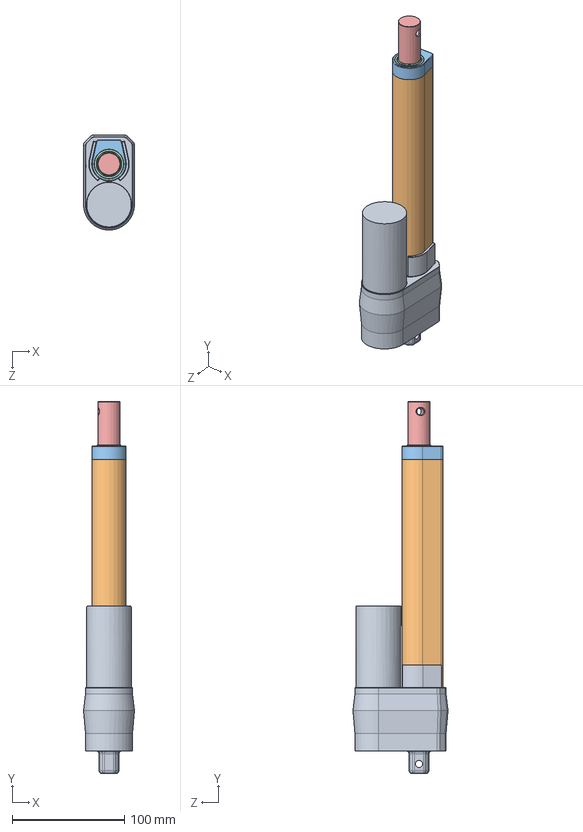
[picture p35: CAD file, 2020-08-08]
Linear Actuator/HDA-6-2.SLDASM
45.5 x 331.6 x 84.8 mm
HDA-BASE
HDA-SHROUD
HDA-SHROUD-CAP
HDA-CAP-SEAL
HDA-STROKE

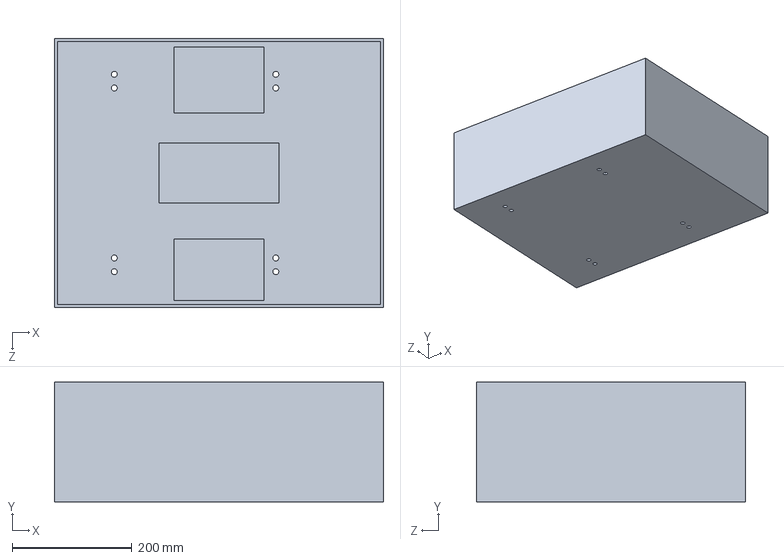
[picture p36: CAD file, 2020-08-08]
Base/Chassis.SLDPRT
550.0 x 200.0 x 450.0 mm

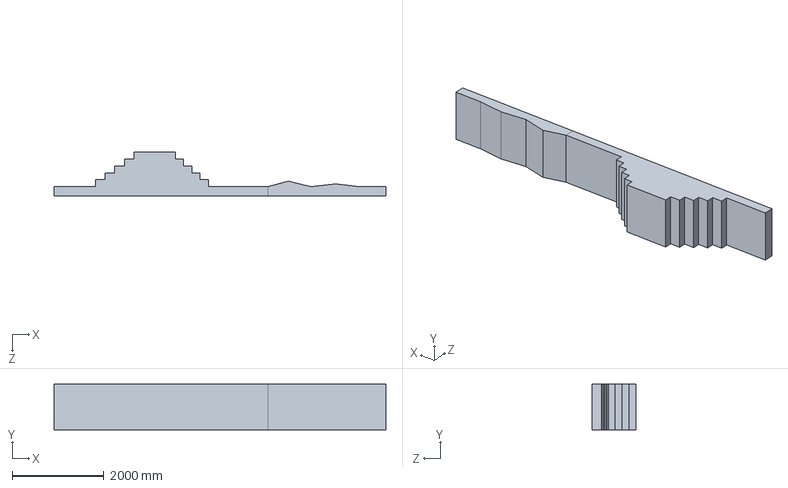
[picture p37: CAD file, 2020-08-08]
Stair Case.SLDPRT
7220.0 x 1000.0 x 950.0 mm

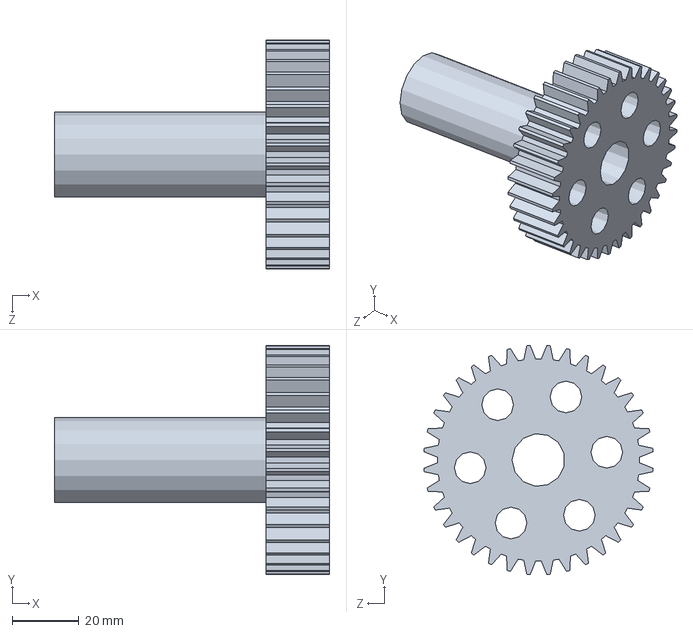
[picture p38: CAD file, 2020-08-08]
Tri Wheel/Gears/Central Tumbling Gear.sldprt
82.6 x 68.8 x 68.8 mm

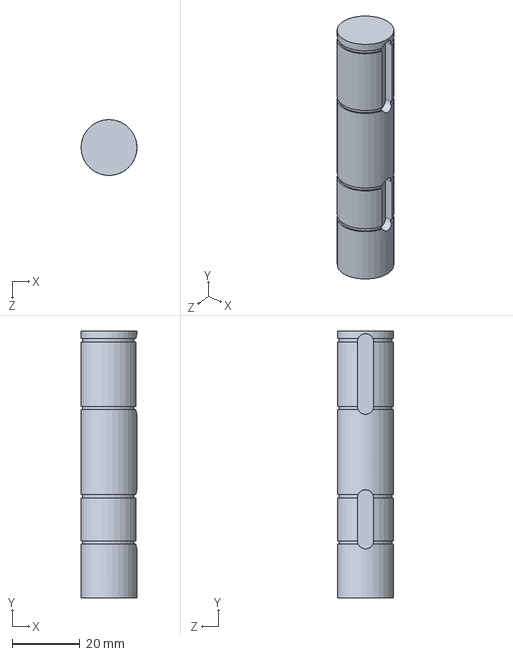
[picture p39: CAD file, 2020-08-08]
Tri Wheel/Shafts/Shaft D1.SLDPRT
16.5 x 78.8 x 16.5 mm

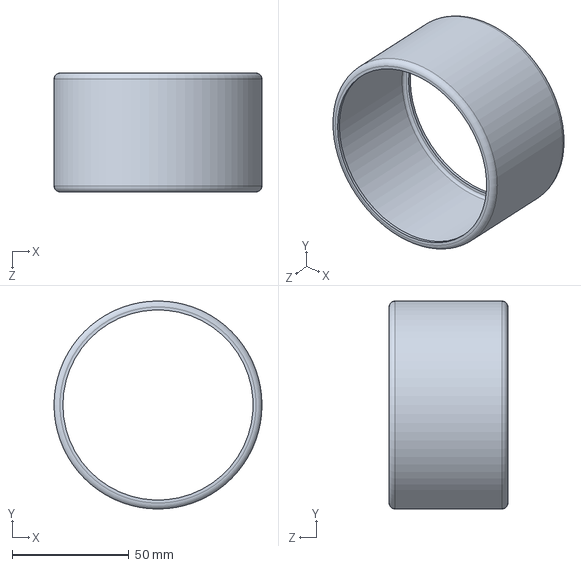
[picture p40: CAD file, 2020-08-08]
Tri Wheel/Wheels/top_wheel.SLDPRT
88.9 x 88.9 x 50.8 mm

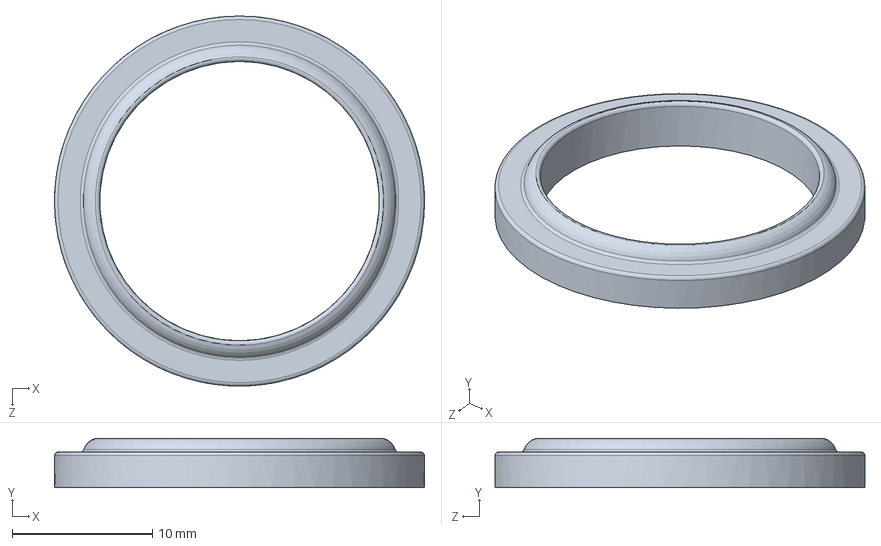
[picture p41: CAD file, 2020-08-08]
Linear Actuator/HDA-CAP-SEAL.SLDPRT
26.4 x 3.52 x 26.4 mm

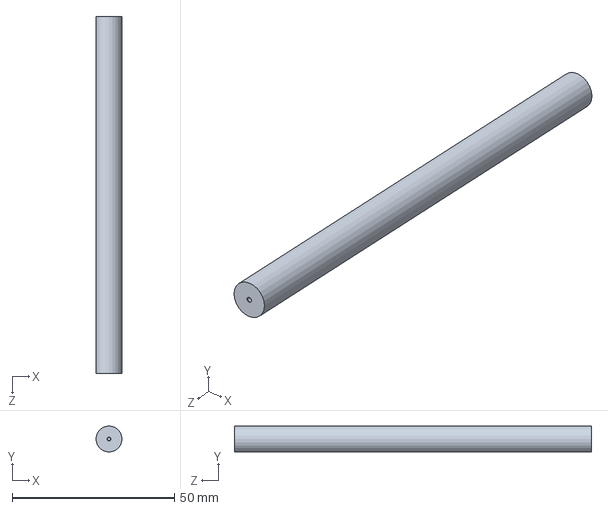
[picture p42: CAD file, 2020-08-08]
Motor Assembly/mil.SLDPRT
8.00 x 8.00 x 110.0 mm

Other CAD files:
Gimbal/Rubber Spacers.sldprt
Base/Chassis_lid.sldprt
Gimbal/Roll Bracket.sldprt
Payload Box/payload_lid.SLDPRT
Gimbal/Bottom Support Plate.sldprt
Gimbal/Camera Support.sldprt
Gimbal/Gimbal.SLDASM
Gimbal/Gimbal.igs
Gimbal/Gimbal.stp
Gimbal/Motor - OH.sldprt
Gimbal/Motor Bracket.sldprt
Gimbal/Motor.sldprt
Gimbal/Pitch Bracket.sldprt
Gimbal/Top Support Plate.sldprt
Linear Actuator/Celvis w-bolt.SLDASM
Linear Actuator/HDA Clevis Mount.SLDPRT
Linear Actuator/HDA-BASE.SLDPRT
Linear Actuator/HDA-SHROUD-CAP.SLDPRT
Linear Actuator/HDA-SHROUD.SLDPRT
Linear Actuator/HDA-STROKE.SLDPRT
Linear Actuator/Shoulder Bolt .25 x 1 - 10-24.SLDPRT
Linear Actuator/_test - w-celvis.IGS
Linear Actuator/_test - w-celvis.SLDASM
Linear Actuator/_test - w-celvis.STEP
Linear Actuator/_test - w-celvis.STL
Motor Assembly/last one.SLDPRT
Motor Assembly/midd.SLDPRT
Motor Assembly/one.SLDPRT
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
